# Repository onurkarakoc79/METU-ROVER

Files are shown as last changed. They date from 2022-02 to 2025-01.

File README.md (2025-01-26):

# METU Rover Project (2019–2022)
# Overview
The METU Rover project focuses on developing advanced robotics solutions for exploration, object detection, and autonomous navigation. During my involvement from 2019 to 2022, I contributed to various aspects of the project, including hardware integration, software development, and algorithm optimization.

# Features

* Object Detection: Implemented temperature-initiated object detection algorithms.
* Autonomous Navigation: Enhanced path planning and obstacle avoidance mechanisms.
* Modular Design: Ensured scalability and modularity in system design.

Setup Instructions
To clone the repository for one of my published modules:

```bash
   git clone https://github.com/onurkarakoc79/METU-ROVER
```
About METU Rover
Learn more about the METU Rover project at METU Rover Website.

<pre> https://meturover.com </pre>

## Contact

If you have any questions, feedback, or inquiries related to the project, feel free to reach out to me:

My personal mail: onurkarakoc79@gmail.com

I appreciate your interest in my projects and look forward to collaborating with you in the fascinating field of scientific exploration and discovery.

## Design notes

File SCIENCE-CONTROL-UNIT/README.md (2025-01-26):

# Metu Rover Science Control Unit

Welcome to the Metu Rover Science Control Unit! This repository contains the control card designs for Metu Rover Team's rover. The control cards play a crucial role in the rover's soil analysis and air sensor functions.

## Soil Analysis Unit

The Soil Analysis Unit is an essential component of the Metu Rover. It is mounted on the rover's back and is responsible for collecting soil data and analyzing it to determine the presence of living organisms. The unit utilizes advanced technologies to gather data and provides valuable insights into the composition and condition of the soil. The results obtained from the soil analysis aid in understanding the viability of potential habitats.

## Air Sensor Antenna

The Air Sensor Antenna is another integral part of Metu Rover's Analysis Unit. This antenna is designed to collect data from the surrounding air and analyze the air quality. By monitoring various parameters such as particulate matter, gases, and other relevant factors, the rover can assess the habitability of the planet or environment it is exploring. The data collected by the Air Sensor Antenna helps researchers and scientists make informed decisions about the suitability of an area for potential exploration or settlement.

## Contact

If you have any questions, feedback, or inquiries related to the project, feel free to reach out to me:

My personal mail: onurkarakoc79@gmail.com

I appreciate your interest in my projects and look forward to collaborating with you in the fascinating field of scientific exploration and discovery.

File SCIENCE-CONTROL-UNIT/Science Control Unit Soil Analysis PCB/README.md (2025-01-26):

# Metu Rover Soil Analysis PCB

## What the PCB is Designed For

The Soil Analysis Box is a crucial component of the Analysis Unit and is responsible for conducting soil analysis on the Metu Rover. The PCB (Printed Circuit Board) described here plays a significant role in controlling and managing various components within the Soil Analysis Box. The key features and functionalities of the Soil Analysis Box are as follows:

Drilling Mechanism: The box includes a driller for digging into the soil.

Vibration Motors: Four small vibration motors and three bmp280 pressure sensors are used to sift the earth and collect soil samples.

Servo Motors: Five servo motors are employed to pour certain chemicals into test tubes.

Stepper Motors: Five small stepper motors and one large stepper motor (Nema23) are used for precise movements and control.

Sensors: The analysis box incorporates three weight sensors, one soil moisture sensor, one temperature sensor, and three bmp280 pressure sensors to measure various soil properties

STM32 Microcontrollers: Two STM32 microcontrollers are utilized for faster processing and pin management. They are connected via UART communication protocol.

Data Transmission: The PCB facilitates the transmission of collected data from sensors to the main computer and subsequently to the base for further analysis.

Motor Control: The PCB determines the operating time of the motors and controls the number of steps the stepper motors will run.

## PCB Description

The PCB design takes into consideration the challenges associated with mounting SMD components and ensures easy replacement of the STM32 Blue Pill boards. The following key aspects are associated with the PCB design:

Dual STM32 Configuration: Two STM32 microcontrollers are utilized to distribute processing load and overcome pin shortage. UART communication is established between the two microcontrollers, with one acting as the primary communicator with the host while waking up the other for specific tasks.

Sensor Readings and Communication: The primary STM32 continuously reads data from the sensors and facilitates communication with the computer. It ensures a steady flow of information between the PCB and the host.

Motor Control: The secondary STM32, which is in a sleep state most of the time for power-saving purposes, determines the operating timing of the motors and controls the steps taken by the stepper motors.

Power and Ground Layers: The PCB consists of two layers, with the top layer dedicated to 5V, 3.3V, and VCC (24V) areas. The bottom layer is entirely covered by the GND line.

Power Supply: The PCB includes a voltage regulator to step down the primary 24V power input to 5V for the necessary sensors. The STM32's internal regulator provides the 3.3V line.

Communication: The PCB utilizes the CAN (Controller Area Network) module for communication with the host.

Motor Control and Integration: Vibration motors are controlled using transistors, while four stepper motor drivers are integrated directly into the circuit. Additionally, an external stepper driver stm is employed to activate the Nema23 large stepper motor.
Please note that this is a high-level overview of the Metu Rover Soil Analysis PCB. For more detailed information and technical specifications, please refer to the relevant documentation.

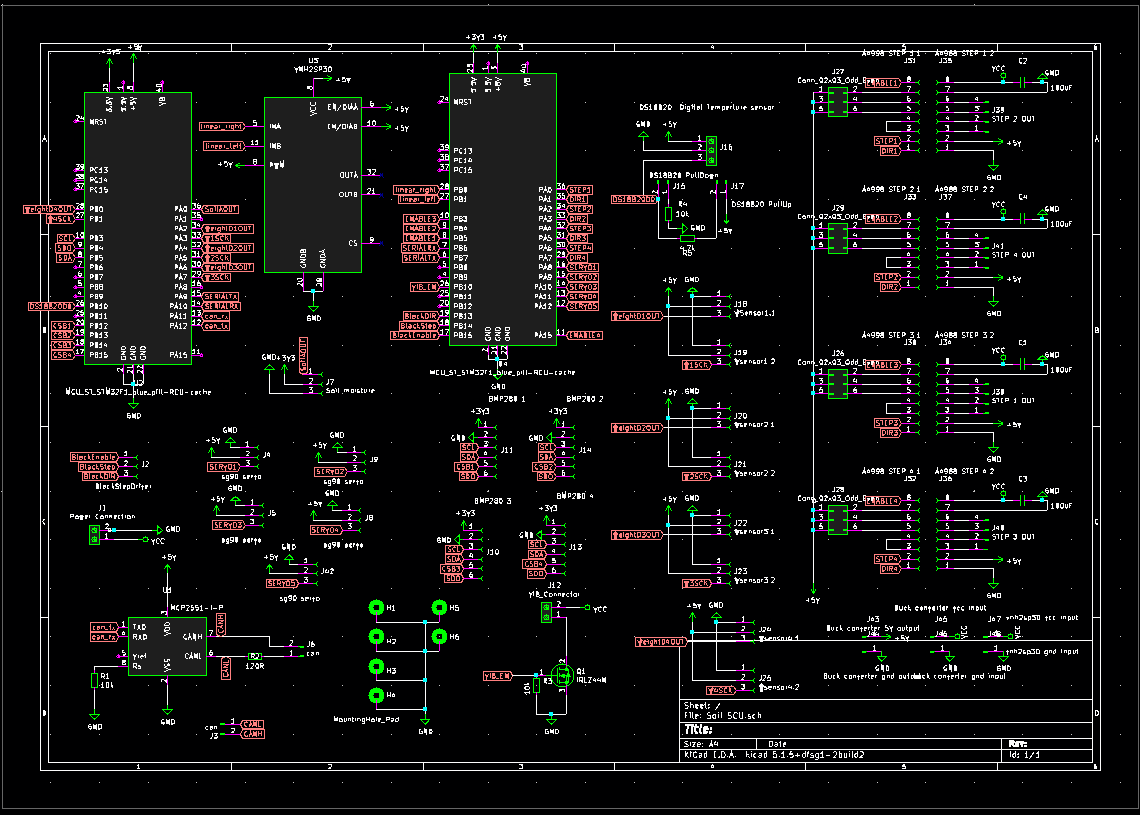
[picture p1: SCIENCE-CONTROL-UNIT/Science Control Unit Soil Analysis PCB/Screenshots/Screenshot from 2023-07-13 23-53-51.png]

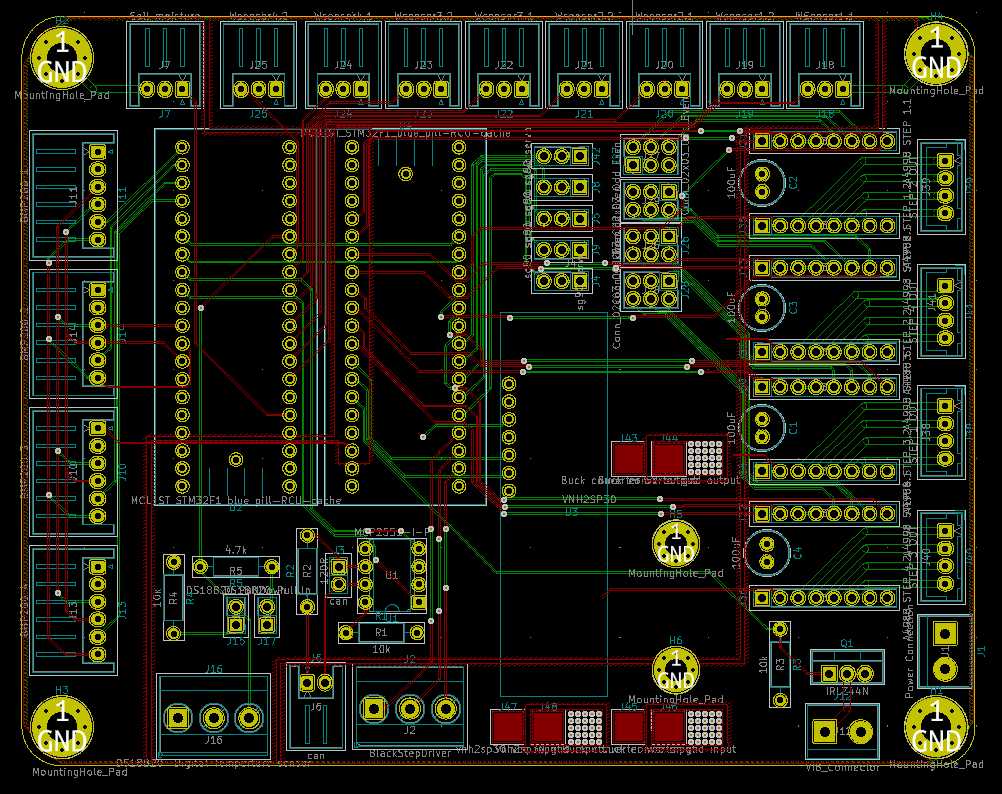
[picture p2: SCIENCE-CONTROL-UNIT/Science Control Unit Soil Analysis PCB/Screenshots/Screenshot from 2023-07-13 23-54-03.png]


## Contact

If you have any questions, feedback, or inquiries related to the project, feel free to reach out to me:

My personal mail: onurkarakoc79@gmail.com

I appreciate your interest in my projects and look forward to collaborating with you in the fascinating field of scientific exploration and discovery.

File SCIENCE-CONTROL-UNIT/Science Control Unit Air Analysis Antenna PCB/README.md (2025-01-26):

# PCB for Antenna Control and Sensor Interface
## What is the PCB Made For

The PCB designed for the antenna serves as a control card, providing essential functionality for the antenna system. It incorporates an STM32 microcontroller, six sensor inputs, and a CAN module for seamless communication with the host system. The antenna system is capable of detecting gases such as CO, CH4, and H2 using these sensors. Additionally, it can measure UV light intensity, airborne dust levels, and accurately determine air temperature and humidity. The STM32 processor reads and organizes the data from the sensors, which is then transmitted to the central control unit via the CAN module. From there, the data flows to the rover host (Nvidia Jetson TX2) and ultimately reaches the central control center with the assistance of Lora communication. The collected data is utilized for the projected thesis or other relevant purposes.

## PCB Description
The PCB designed for the antenna system exhibits a straightforward structure with the following features:

Sensor Inputs: The PCB provides six JST inputs for connecting the sensors. To ensure compatibility with the 3.3V operating voltage of the STM32 microcontroller, a voltage divider is implemented for sensor outputs that typically work with 5 volts.

Layer Structure: The PCB follows a 2-layer design. The first layer is dedicated to the 5V field, while the second layer is covered with the GND field, establishing a proper grounding structure.

Power Supply: Although the main power input to the PCB is 24V, a voltage regulator is employed to reduce the voltage to 5V, which is then supplied to the sensors. This ensures the sensors operate within their specified voltage range.

Interchangeability and Assembly: Instead of utilizing SMD components, the PCB is designed to accommodate female header pins, enabling easy assembly and interchangeability. This design choice allows the PCB to function as a basic breadboard and facilitates the placement of a ready-made STM32 Blue Pill module on it. 

As a result, the system can be used without the need for voltage level conversion from 5V to 3.3V for the STM32 microcontroller.
Please note that this is a summary of the key features of the antenna PCB. For more detailed technical specifications and information, please refer to the relevant documentation.

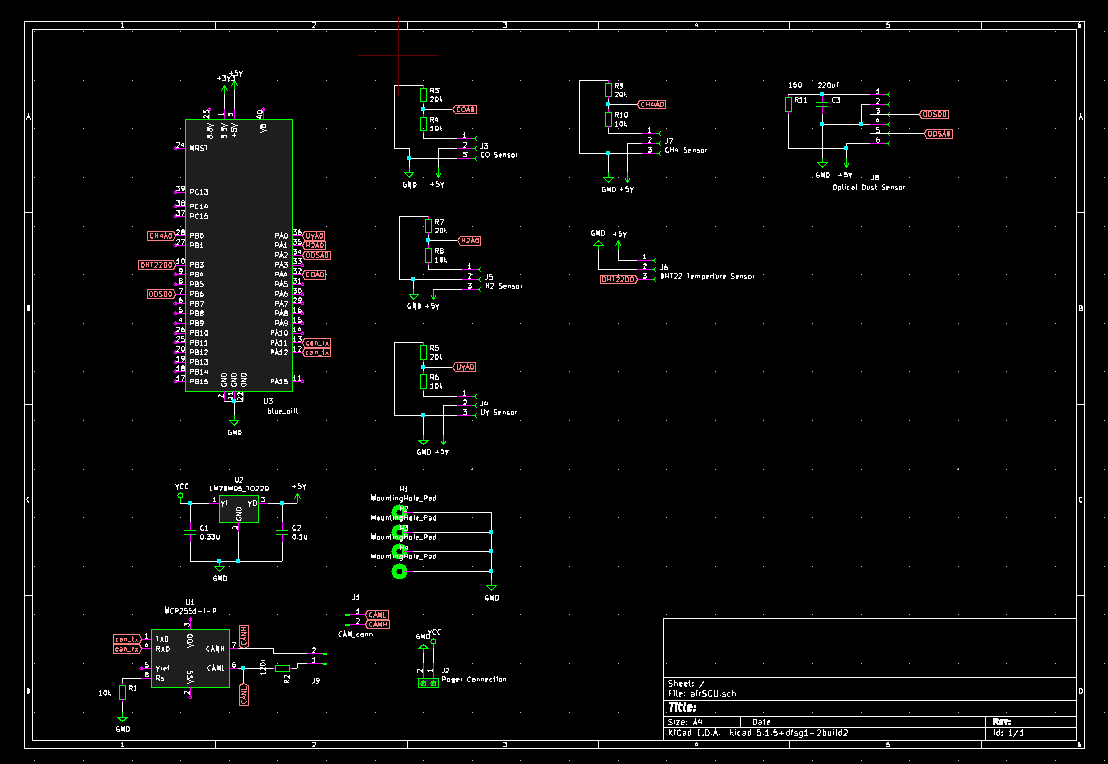
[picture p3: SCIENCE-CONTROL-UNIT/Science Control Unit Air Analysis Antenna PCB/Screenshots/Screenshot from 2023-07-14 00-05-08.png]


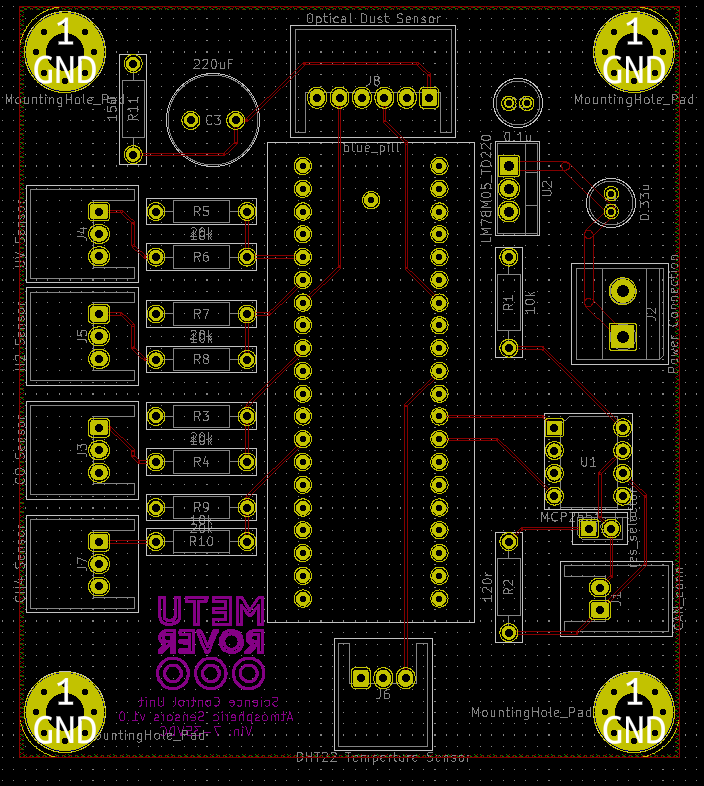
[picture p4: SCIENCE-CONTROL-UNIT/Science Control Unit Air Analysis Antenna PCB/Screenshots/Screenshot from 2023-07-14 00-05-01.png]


## Contact

If you have any questions, feedback, or inquiries related to the project, feel free to reach out to me:

My personal mail: onurkarakoc79@gmail.com

I appreciate your interest in my projects and look forward to collaborating with you in the fascinating field of scientific exploration and discovery.

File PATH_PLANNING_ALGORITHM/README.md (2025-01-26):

# Computer Vision Rover Path Planning

This is a path planning code for a rover developed using Python. The code utilizes Dijkstra's algorithm to find the shortest path between a given start point and an endpoint, considering obstacles in the environment. It is designed to work with images as input for computer vision applications.

## Features

- Calculation of the shortest path using Dijkstra's algorithm
- Handling of obstacles defined as convex shapes
- Visualization of the path on an input image
- Integration with computer vision applications

## Prerequisites

- Python 3. x

## Installation

1. Clone the repository to your local machine:

```bash
   git clone https://github.com/onurkarakoc79/METU-ROVER.git
```

3. Install requirement libraries
pip install -r requirements.txt

Usage
Configure the map and obstacle settings in the main() function of the Map.py file.
Prepare an input image of the map on which you want to perform path planning.
Run the path planning code:
shell
Copy code

python3 Map.py

After executing the Map.py file you don't need to execute it every time unless the map was changed.
After that execute the VisualwithClick.py file
Copy code

python3 VisualwithClick.py

Click on the image to specify the start and end points.
The calculated path will be displayed on the image.
You can close the window with the ESC button.

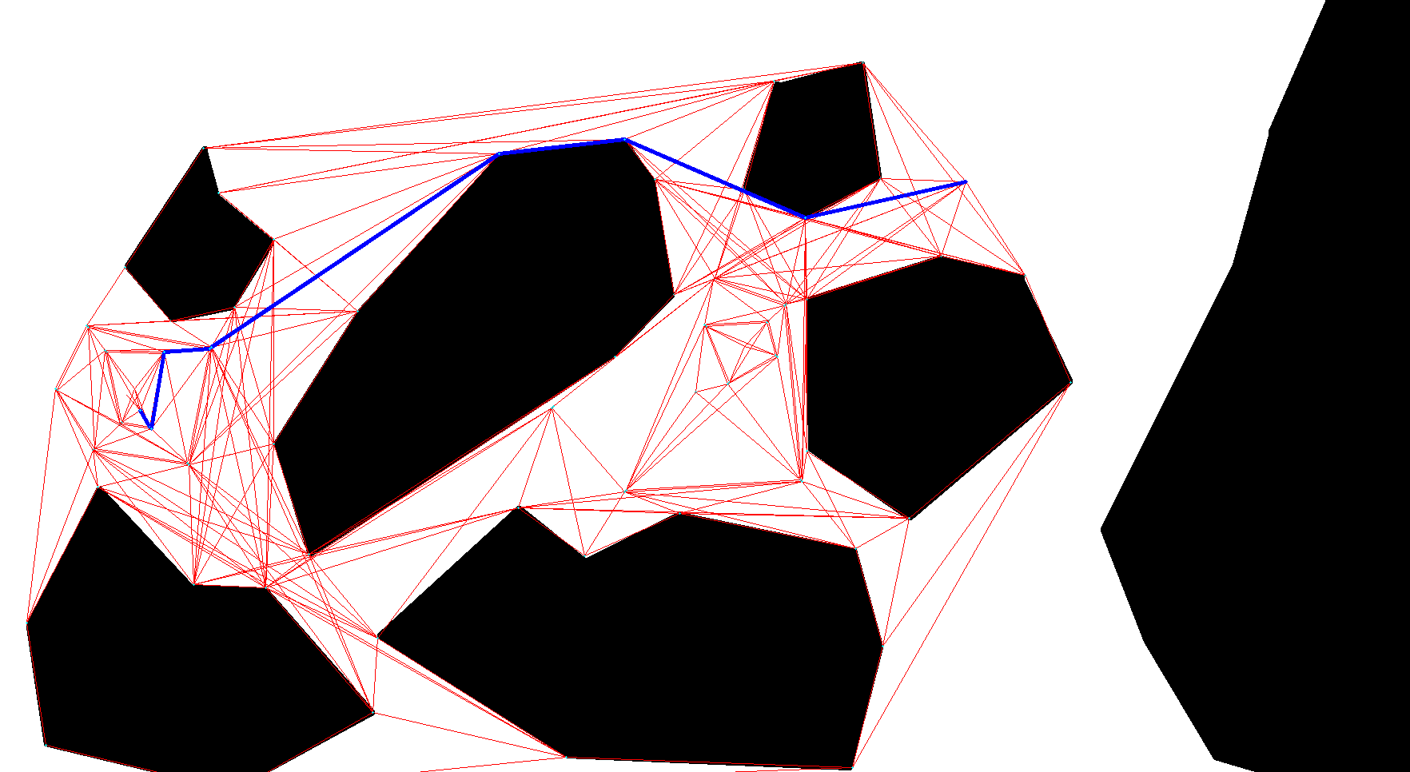
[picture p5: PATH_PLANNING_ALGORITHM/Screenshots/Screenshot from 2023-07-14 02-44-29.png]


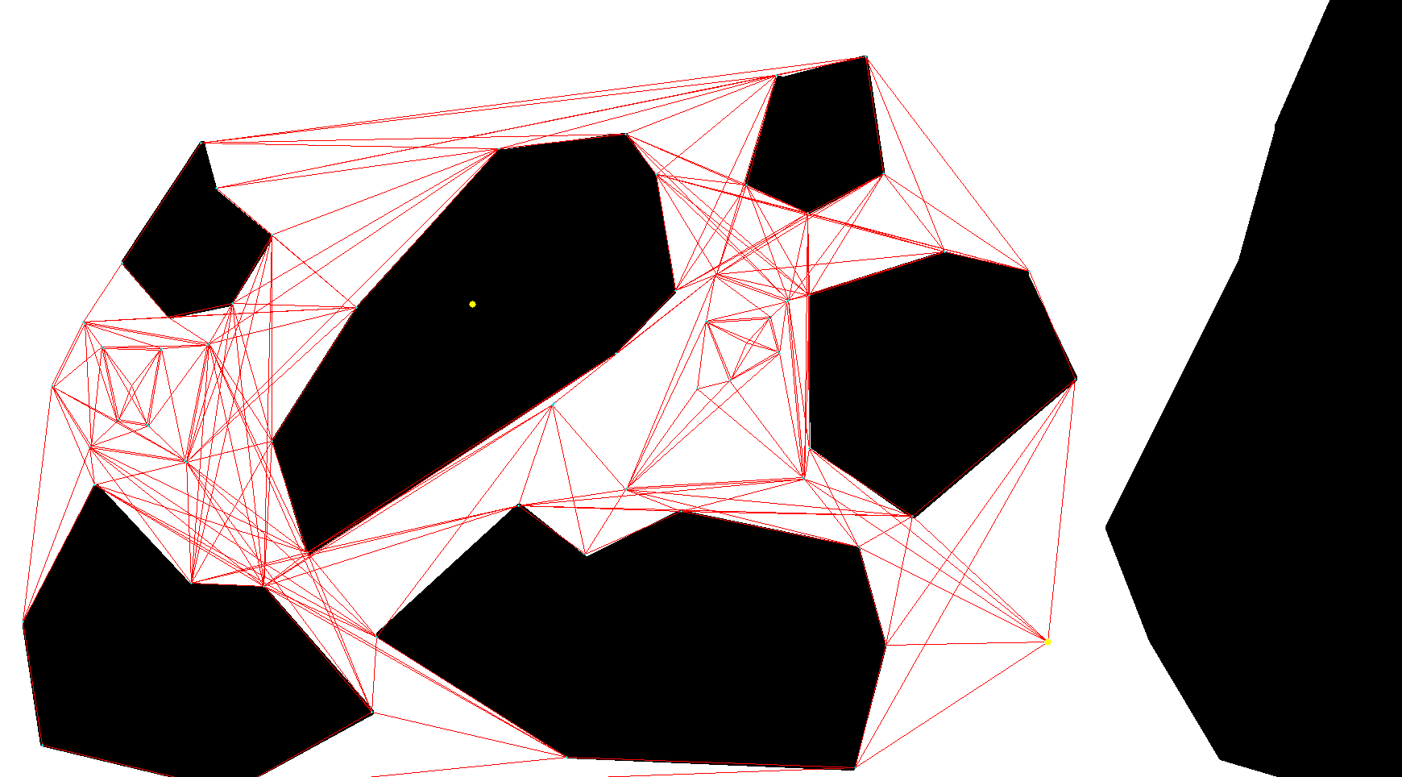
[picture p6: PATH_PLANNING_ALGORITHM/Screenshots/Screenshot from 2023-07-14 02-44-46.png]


## Contact

If you have any questions, feedback, or inquiries related to the project, feel free to reach out to me:

My personal mail: onurkarakoc79@gmail.com

I appreciate your interest in my projects and look forward to collaborating with you in the fascinating field of scientific exploration and discovery.

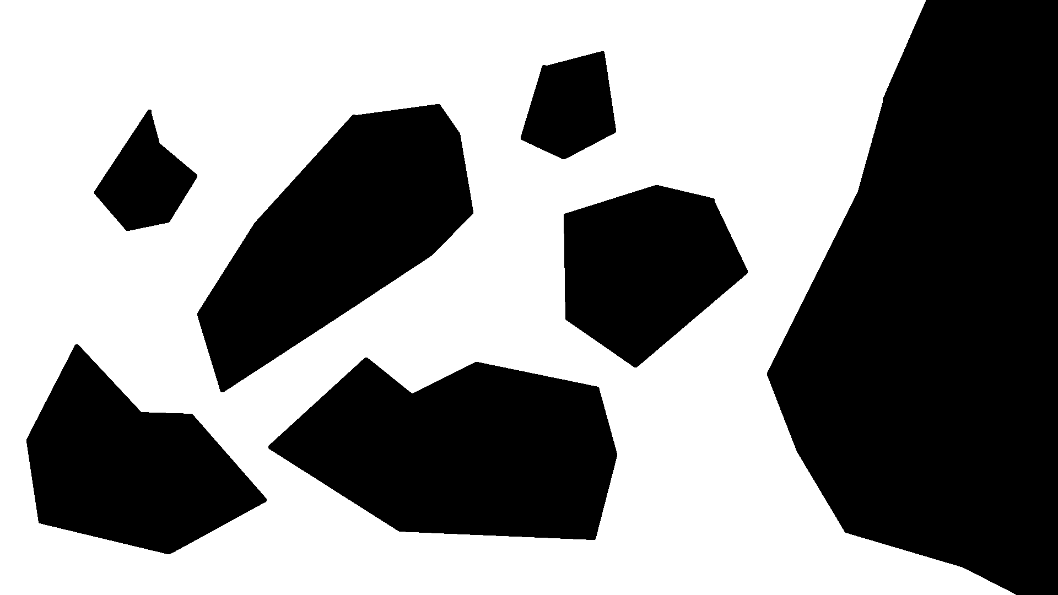
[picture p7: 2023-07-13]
PATH_PLANNING_ALGORITHM/map_01.png

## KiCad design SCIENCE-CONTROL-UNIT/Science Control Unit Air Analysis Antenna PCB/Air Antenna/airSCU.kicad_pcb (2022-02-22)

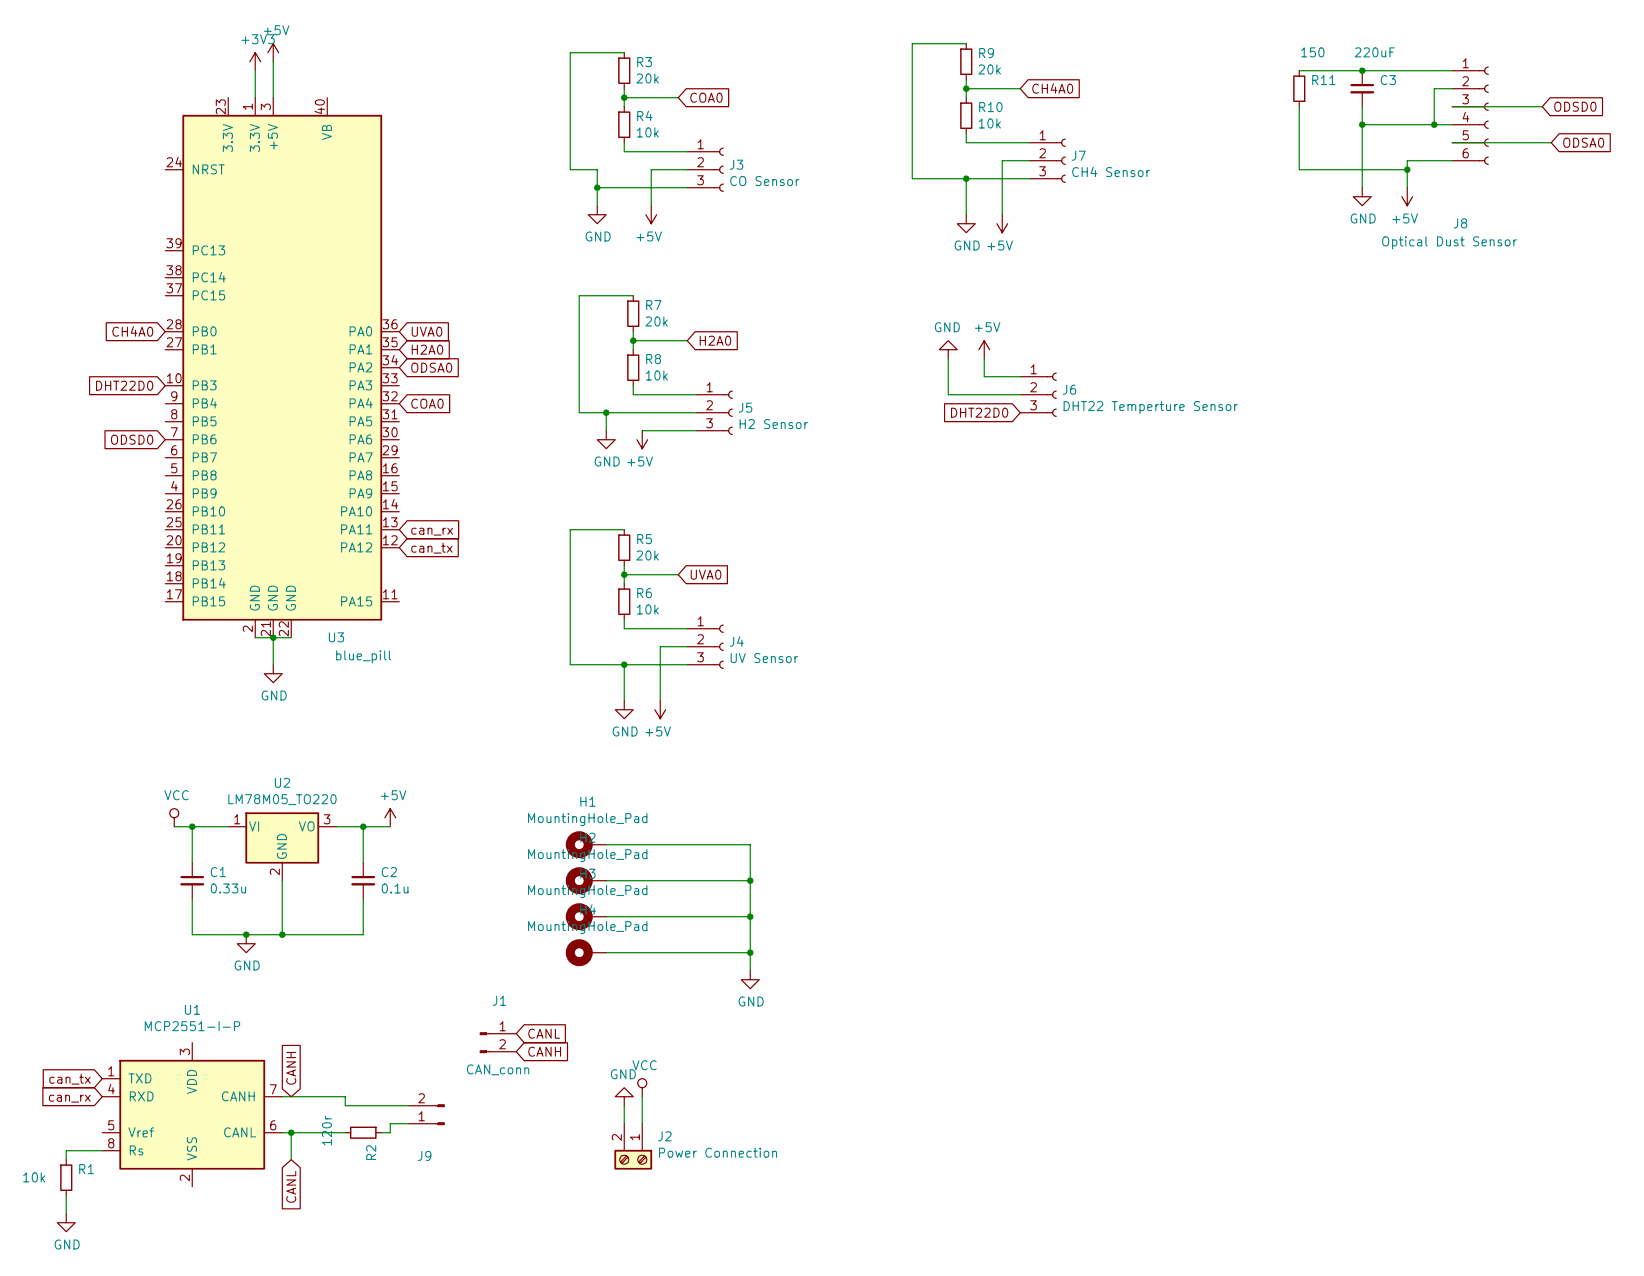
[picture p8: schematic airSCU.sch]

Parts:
C1: 0.33u; C_Radial_D5.0mm_H5.0mm_P2.00mm
C2: 0.1u; C_Radial_D5.0mm_H5.0mm_P2.00mm
C3: 220uF; C_Radial_D10.0mm_H12.5mm_P5.00mm
H1, H2, H3, H4: MountingHole_Pad; MountingHole_4.3mm_M4_Pad_Via
J1: CAN_conn; JST_XH_S2B-XH-A-1_1x02_P2.50mm_Horizontal
J2: Power Connection; TerminalBlock_Phoenix_MKDS-1,5-2-5.08_1x02_P5.08mm_Horizont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
J3: CO Sensor; JST_XH_S3B-XH-A-1_1x03_P2.50mm_Horizontal
J4: UV Sensor; JST_XH_S3B-XH-A-1_1x03_P2.50mm_Horizontal
J5: H2 Sensor; JST_XH_S3B-XH-A-1_1x03_P2.50mm_Horizontal
J6: DHT22 Temperture Sensor; JST_XH_S3B-XH-A-1_1x03_P2.50mm_Horizontal
J7: CH4 Sensor; JST_XH_S3B-XH-A-1_1x03_P2.50mm_Horizontal
J8: Optical Dust Sensor; JST_XH_S6B-XH-A-1_1x06_P2.50mm_Horizontal
J9: res_selector; PinHeader_1x02_P2.54mm_Vertical
R1, R4, R6, R8, R10: 10k; R_Axial_DIN0207_L6.3mm_D2.5mm_P10.16mm_Horizontal
R2: 120r; R_Axial_DIN0207_L6.3mm_D2.5mm_P10.16mm_Horizontal
R3, R5, R7, R9: 20k; R_Axial_DIN0207_L6.3mm_D2.5mm_P10.16mm_Horizontal
R11: 150; R_Axial_DIN0207_L6.3mm_D2.5mm_P10.16mm_Horizontal
U1: MCP2551-I-P; DIP-8_W7.62mm
U2: LM78M05_TO220; TO-220-3_Vertical
U3: blue_pill

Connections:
+3V3: U3.1 (3.3V)
+5V: C2.1, J3.2, J4.2, J5.3, J6.1, J7.2, J8.6, R11.1, U2.3 (VO), U3.3 (+5V)
CANH: J1.2, J9.2, U1.7 (CANH)
CANL: J1.1, R2.2, U1.6 (CANL)
CH4A0: R9.2, R10.1, U3.28 (PB0)
COA0: R3.2, R4.1, U3.32 (PA4)
DHT22D0: J6.3, U3.10 (PB3)
GND: C1.2, C2.2, C3.2, H1.1, H2.1, H3.1, H4.1, J2.2, J3.3, J4.3, J5.2, J6.2, J7.3, J8.2, J8.4, R1.2, R3.1, R5.1, R7.1, R9.1, U2.2 (GND), U3.2 (GND), U3.21 (GND), U3.22 (GND)
H2A0: R7.2, R8.1, U3.35 (PA1)
unnamed: C3.1, J8.1, R11.2
unnamed: J3.1, R4.2
unnamed: J4.1, R6.2
unnamed: J5.1, R8.2
unnamed: J7.1, R10.2
unnamed: J9.1, R2.1
unnamed: R1.1, U1.8 (Rs)
ODSA0: J8.5, U3.34 (PA2)
ODSD0: J8.3, U3.7 (PB6)
UVA0: R5.2, R6.1, U3.36 (PA0)
VCC: C1.1, J2.1, U2.1 (VI)
can_rx: U1.4 (RXD), U3.13 (PA11)
can_tx: U1.1 (TXD), U3.12 (PA12)

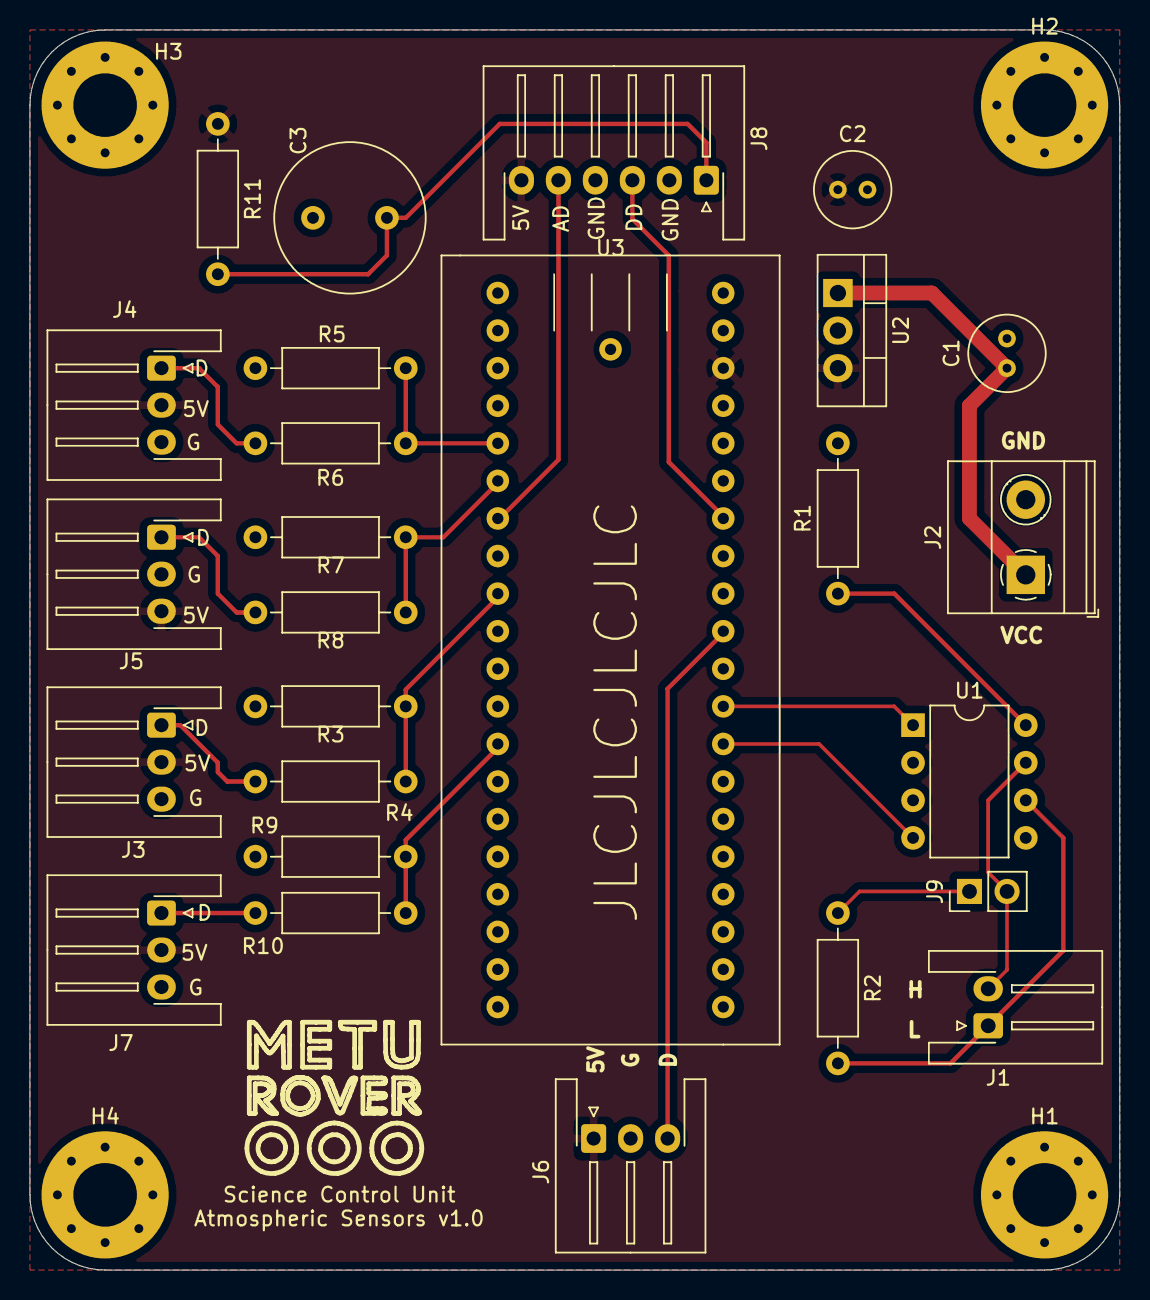
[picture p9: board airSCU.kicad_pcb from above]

Board: 2 copper layers, 73.7 x 83.8 mm, 30 parts (0 on the bottom side), 21 nets.

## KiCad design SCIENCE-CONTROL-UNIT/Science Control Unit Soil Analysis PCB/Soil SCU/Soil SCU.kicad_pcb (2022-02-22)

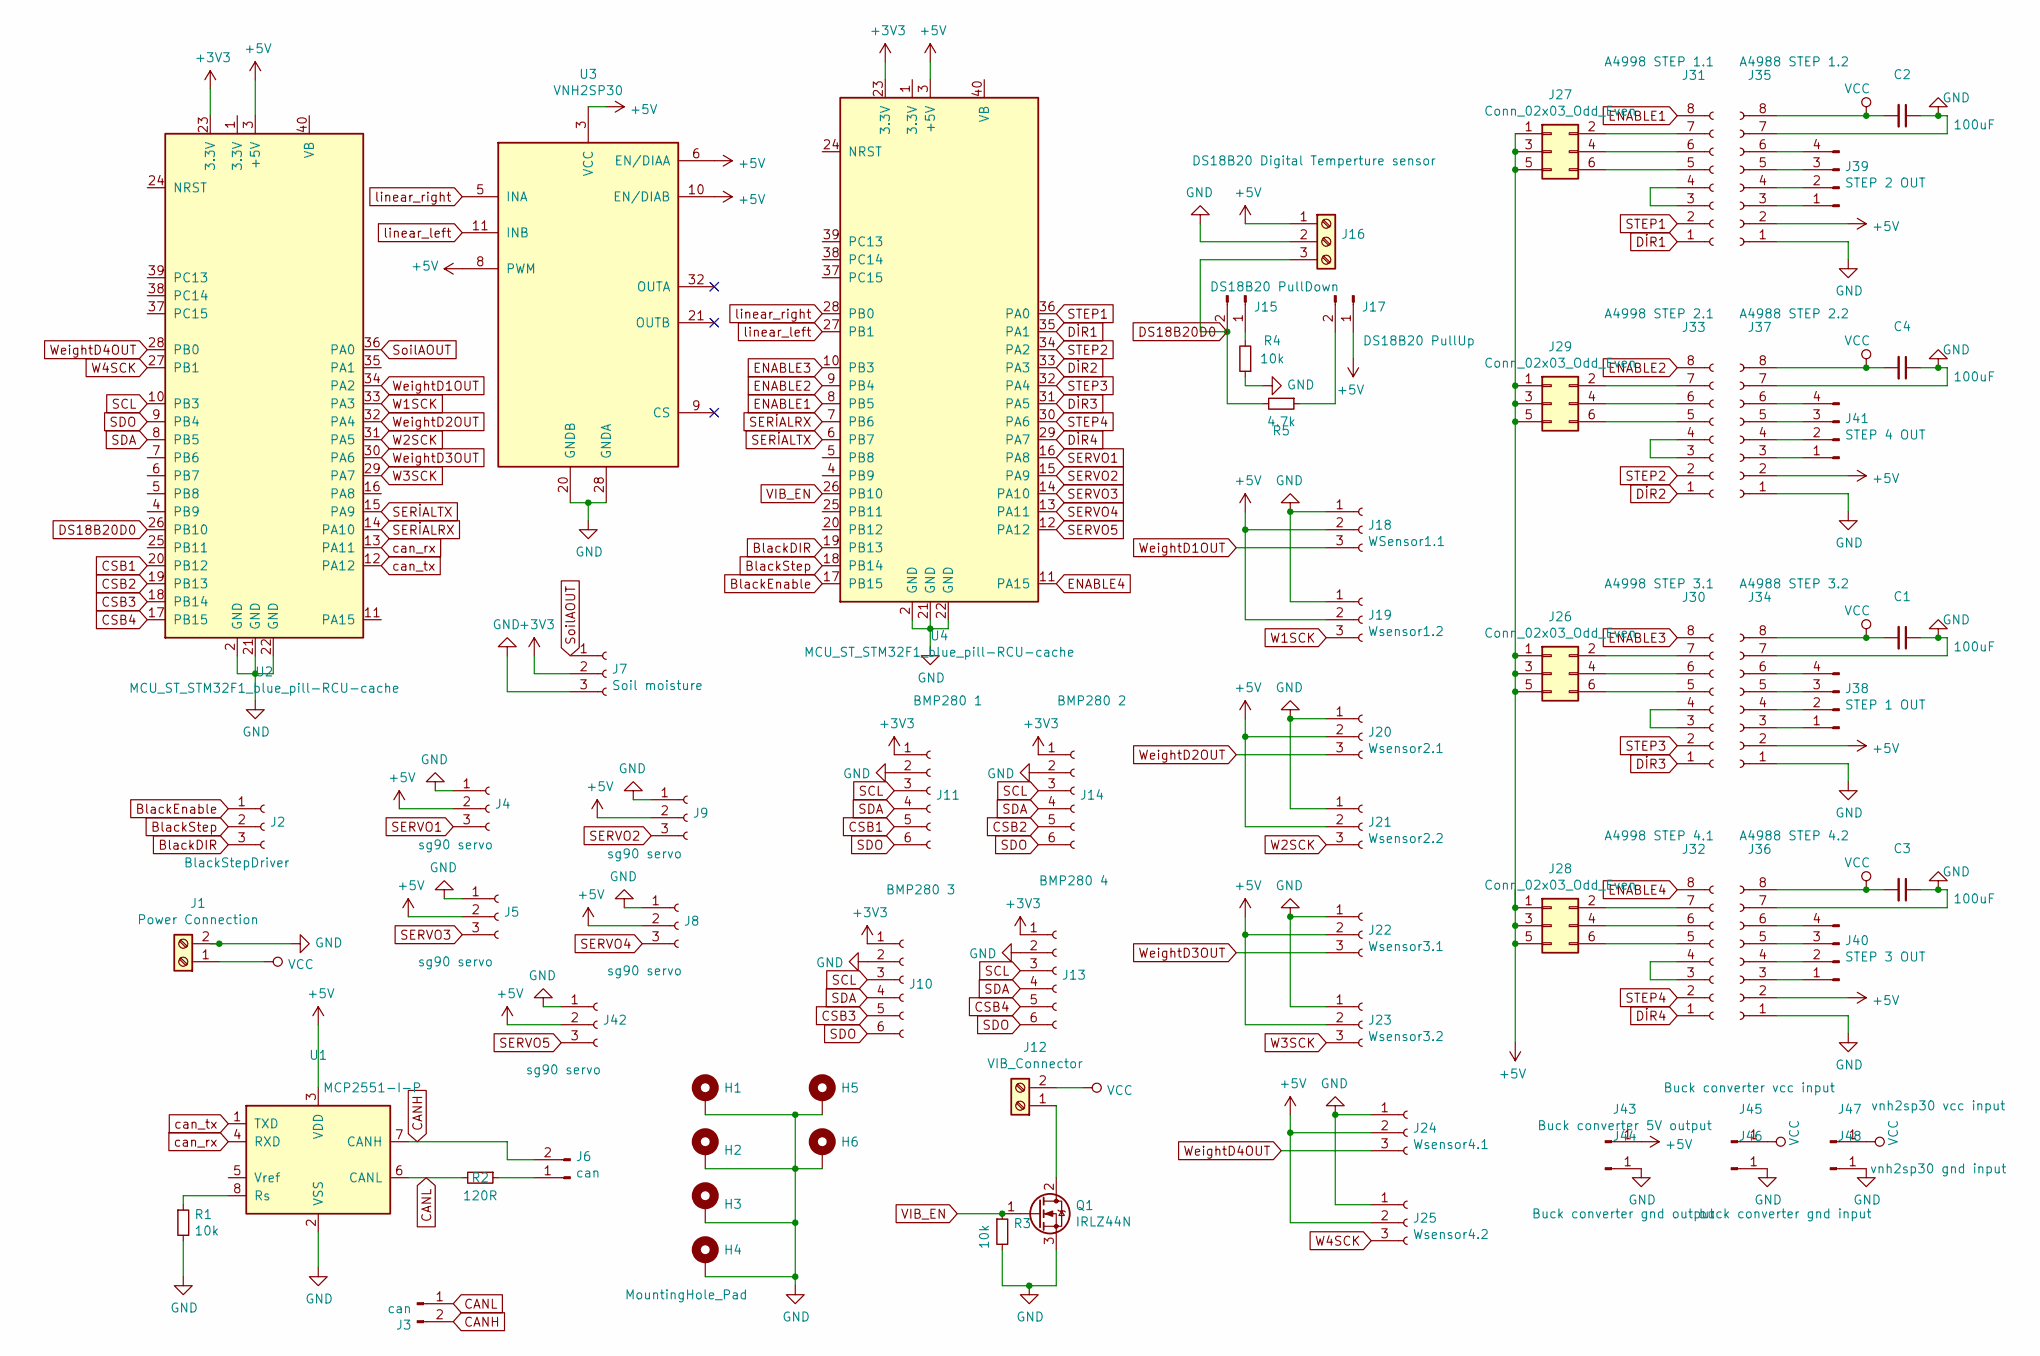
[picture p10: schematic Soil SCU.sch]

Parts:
C1, C2, C3, C4: 100uF; C_Radial_D6.3mm_H11.0mm_P2.50mm
H1, H2, H3, H4: MountingHole_Pad; MountingHole_4.3mm_M4_Pad_Via
H5, H6: MountingHole_Pad; MountingHole_3.2mm_M3_Pad_Via
J1: Power Connection; TerminalBlock_bornier-2_P5.08mm
J2: BlackStepDriver; TerminalBlock_Phoenix_MKDS-3-3-5.08_1x03_P5.08mm_Horizontal
J3: can; PinHeader_1x02_P2.54mm_Vertical
J4, J5, J8, J9, J42: sg90 servo; PinHeader_1x03_P2.54mm_Vertical
J6: can; JST_XH_S2B-XH-A_1x02_P2.50mm_Horizontal
J7: Soil moisture; JST_XH_S3B-XH-A_1x03_P2.50mm_Horizontal
J10: BMP280 3; JST_XH_S6B-XH-A_1x06_P2.50mm_Horizontal
J11: BMP280 1; JST_XH_S6B-XH-A_1x06_P2.50mm_Horizontal
J12: VIB_Connector; TerminalBlock_bornier-2_P5.08mm
J13: BMP280 4; JST_XH_S6B-XH-A_1x06_P2.50mm_Horizontal
J14: BMP280 2; JST_XH_S6B-XH-A_1x06_P2.50mm_Horizontal
J15: DS18B20 PullDown; PinHeader_1x02_P2.54mm_Vertical
J16: DS18B20 Digital Temperture sensor; TerminalBlock_Phoenix_MKDS-3-3-5.08_1x03_P5.08mm_Horizontal
J17: DS18B20 PullUp; PinHeader_1x02_P2.54mm_Vertical
J18: WSensor1.1; JST_XH_S3B-XH-A_1x03_P2.50mm_Horizontal
J19: Wsensor1.2; JST_XH_S3B-XH-A_1x03_P2.50mm_Horizontal
J20: Wsensor2.1; JST_XH_S3B-XH-A_1x03_P2.50mm_Horizontal
J21: Wsensor2.2; JST_XH_S3B-XH-A_1x03_P2.50mm_Horizontal
J22: Wsensor3.1; JST_XH_S3B-XH-A_1x03_P2.50mm_Horizontal
J23: Wsensor3.2; JST_XH_S3B-XH-A_1x03_P2.50mm_Horizontal
J24: Wsensor4.1; JST_XH_S3B-XH-A_1x03_P2.50mm_Horizontal
J25: Wsensor4.2; JST_XH_S3B-XH-A_1x03_P2.50mm_Horizontal
J26, J27, J28, J29: Conn_02x03_Odd_Even; PinHeader_2x03_P2.54mm_Vertical
J30: A4998 STEP 3.1; PinSocket_1x08_P2.54mm_Vertical
J31: A4998 STEP 1.1; PinSocket_1x08_P2.54mm_Vertical
J32: A4998 STEP 4.1; PinSocket_1x08_P2.54mm_Vertical
J33: A4998 STEP 2.1; PinSocket_1x08_P2.54mm_Vertical
J34: A4988 STEP 3.2; PinSocket_1x08_P2.54mm_Vertical
J35: A4988 STEP 1.2; PinSocket_1x08_P2.54mm_Vertical
J36: A4988 STEP 4.2; PinSocket_1x08_P2.54mm_Vertical
J37: A4988 STEP 2.2; PinSocket_1x08_P2.54mm_Vertical
J38: STEP 1 OUT; JST_XH_B4B-XH-A_1x04_P2.50mm_Vertical
J39: STEP 2 OUT; JST_XH_B4B-XH-A_1x04_P2.50mm_Vertical
J40: STEP 3 OUT; JST_XH_B4B-XH-A_1x04_P2.50mm_Vertical
J41: STEP 4 OUT; JST_XH_B4B-XH-A_1x04_P2.50mm_Vertical
J43: Buck converter 5V output; TestPoint_Pad_4.0x4.0mm
J44: Buck converter gnd output; TestPoint_Pad_4.0x4.0mm
J45: Buck converter vcc input; TestPoint_Pad_4.0x4.0mm
J46: buck converter gnd input; TestPoint_Pad_4.0x4.0mm
J47: vnh2sp30 vcc input; TestPoint_Pad_4.0x4.0mm
J48: vnh2sp30 gnd input; TestPoint_Pad_4.0x4.0mm
Q1: IRLZ44N; TO-220-3_Vertical
R1, R3, R4: 10k; R_Axial_DIN0207_L6.3mm_D2.5mm_P10.16mm_Horizontal
R2: 120R; R_Axial_DIN0207_L6.3mm_D2.5mm_P10.16mm_Horizontal
R5: 4.7k; R_Axial_DIN0207_L6.3mm_D2.5mm_P10.16mm_Horizontal
U1: MCP2551-I-P; DIP-8_W7.62mm
U2, U4: MCU_ST_STM32F1_blue_pill-RCU-cache; blue_pill
U3: VNH2SP30; vnh_vertical

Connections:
+3V3: J7.2, J10.1, J11.1, J13.1, J14.1, U2.23 (3.3V), U4.23 (3.3V)
+5V: J4.2, J5.2, J8.2, J9.2, J16.1, J17.1, J18.2, J19.2, J20.2, J21.2, J22.2, J23.2, J24.2, J25.2, J26.1, J26.3, J26.5, J27.1, J27.3, J27.5, J28.1, J28.3, J28.5, J29.1, J29.3, J29.5, J34.2, J35.2, J36.2, J37.2, J42.2, J43.1, U1.3 (VDD), U2.3 (+5V), U3.3 (VCC), U3.6 (EN/DIAA), U3.8 (PWM), U3.10 (EN/DIAB), U3.13 (VCC), U3.23 (VCC), U3.31 (VCC), U4.3 (+5V)
BlackDIR: J2.3, U4.19 (PB13)
BlackEnable: J2.1, U4.17 (PB15)
BlackStep: J2.2, U4.18 (PB14)
CANH: J3.2, J6.2, U1.7 (CANH)
CANL: J3.1, R2.2, U1.6 (CANL)
CSB1: J11.5, U2.20 (PB12)
CSB2: J14.5, U2.19 (PB13)
CSB3: J10.5, U2.18 (PB14)
CSB4: J13.5, U2.17 (PB15)
DS18B20D0: J15.2, J16.3, R5.2, U2.26 (PB10)
DİR1: J31.1, U4.35 (PA1)
DİR2: J33.1, U4.33 (PA3)
DİR3: J30.1, U4.31 (PA5)
DİR4: J32.1, U4.29 (PA7)
ENABLE1: J31.8, U4.8 (PB5)
ENABLE2: J33.8, U4.9 (PB4)
ENABLE3: J30.8, U4.10 (PB3)
ENABLE4: J32.8, U4.11 (PA15)
GND: C1.1, C2.1, C3.1, C4.1, H1.1, H2.1, H3.1, H4.1, H5.1, H6.1, J1.2, J4.1, J5.1, J7.3, J8.1, J9.1, J10.2, J11.2, J13.2, J14.2, J16.2, J18.1, J19.1, J20.1, J21.1, J22.1, J23.1, J24.1, J25.1, J34.1, J34.7, J35.1, J35.7, J36.1, J36.7, J37.1, J37.7, J42.1, J44.1, J46.1, J48.1, Q1.3 (S), R1.2, R3.2, R4.1, U1.2 (VSS), U2.2 (GND), U2.21 (GND), U2.22 (GND), U3.18 (GNDB), U3.19 (GNDB), U3.20 (GNDB), U3.26 (GNDA), U3.27 (GNDA), U3.28 (GNDA), U4.2 (GND), U4.21 (GND), U4.22 (GND)
unnamed: J6.1, R2.1
unnamed: J12.1, Q1.2 (D)
unnamed: J15.1, R4.2
unnamed: J17.2, R5.1
unnamed: J26.2, J30.7
unnamed: J26.4, J30.6
unnamed: J26.6, J30.5
unnamed: J27.2, J31.7
unnamed: J27.4, J31.6
unnamed: J27.6, J31.5
unnamed: J28.2, J32.7
unnamed: J28.4, J32.6
unnamed: J28.6, J32.5
unnamed: J29.2, J33.7
unnamed: J29.4, J33.6
unnamed: J29.6, J33.5
unnamed: J30.3, J30.4
unnamed: J31.3, J31.4
unnamed: J32.3, J32.4
unnamed: J33.3, J33.4
unnamed: J34.3, J38.1
unnamed: J34.4, J38.2
unnamed: J34.5, J38.3
unnamed: J34.6, J38.4
unnamed: J35.3, J39.1
unnamed: J35.4, J39.2
unnamed: J35.5, J39.3
unnamed: J35.6, J39.4
unnamed: J36.3, J40.1
unnamed: J36.4, J40.2
unnamed: J36.5, J40.3
unnamed: J36.6, J40.4
unnamed: J37.3, J41.1
unnamed: J37.4, J41.2
unnamed: J37.5, J41.3
unnamed: J37.6, J41.4
unnamed: R1.1, U1.8 (Rs)
SCL: J10.3, J11.3, J13.3, J14.3, U2.10 (PB3)
SDA: J10.4, J11.4, J13.4, J14.4, U2.8 (PB5)
SDO: J10.6, J11.6, J13.6, J14.6, U2.9 (PB4)
SERVO1: J4.3, U4.16 (PA8)
SERVO2: J9.3, U4.15 (PA9)
SERVO3: J5.3, U4.14 (PA10)
SERVO4: J8.3, U4.13 (PA11)
SERVO5: J42.3, U4.12 (PA12)
SERİALRX: U2.14 (PA10), U4.7 (PB6)
SERİALTX: U2.15 (PA9), U4.6 (PB7)
STEP1: J31.2, U4.36 (PA0)
STEP2: J33.2, U4.34 (PA2)
STEP3: J30.2, U4.32 (PA4)
STEP4: J32.2, U4.30 (PA6)
SoilAOUT: J7.1, U2.36 (PA0)
VCC: C1.2, C2.2, C3.2, C4.2, J1.1, J12.2, J34.8, J35.8, J36.8, J37.8, J45.1, J47.1
VIB_EN: Q1.1 (G), R3.1, U4.26 (PB10)
W1SCK: J19.3, U2.33 (PA3)
W2SCK: J21.3, U2.31 (PA5)
W3SCK: J23.3, U2.29 (PA7)
W4SCK: J25.3, U2.27 (PB1)
WeightD1OUT: J18.3, U2.34 (PA2)
WeightD2OUT: J20.3, U2.32 (PA4)
WeightD3OUT: J22.3, U2.30 (PA6)
WeightD4OUT: J24.3, U2.28 (PB0)
can_rx: U1.4 (RXD), U2.13 (PA11)
can_tx: U1.1 (TXD), U2.12 (PA12)
linear_left: U3.11 (INB), U4.27 (PB1)
linear_right: U3.5 (INA), U4.28 (PB0)

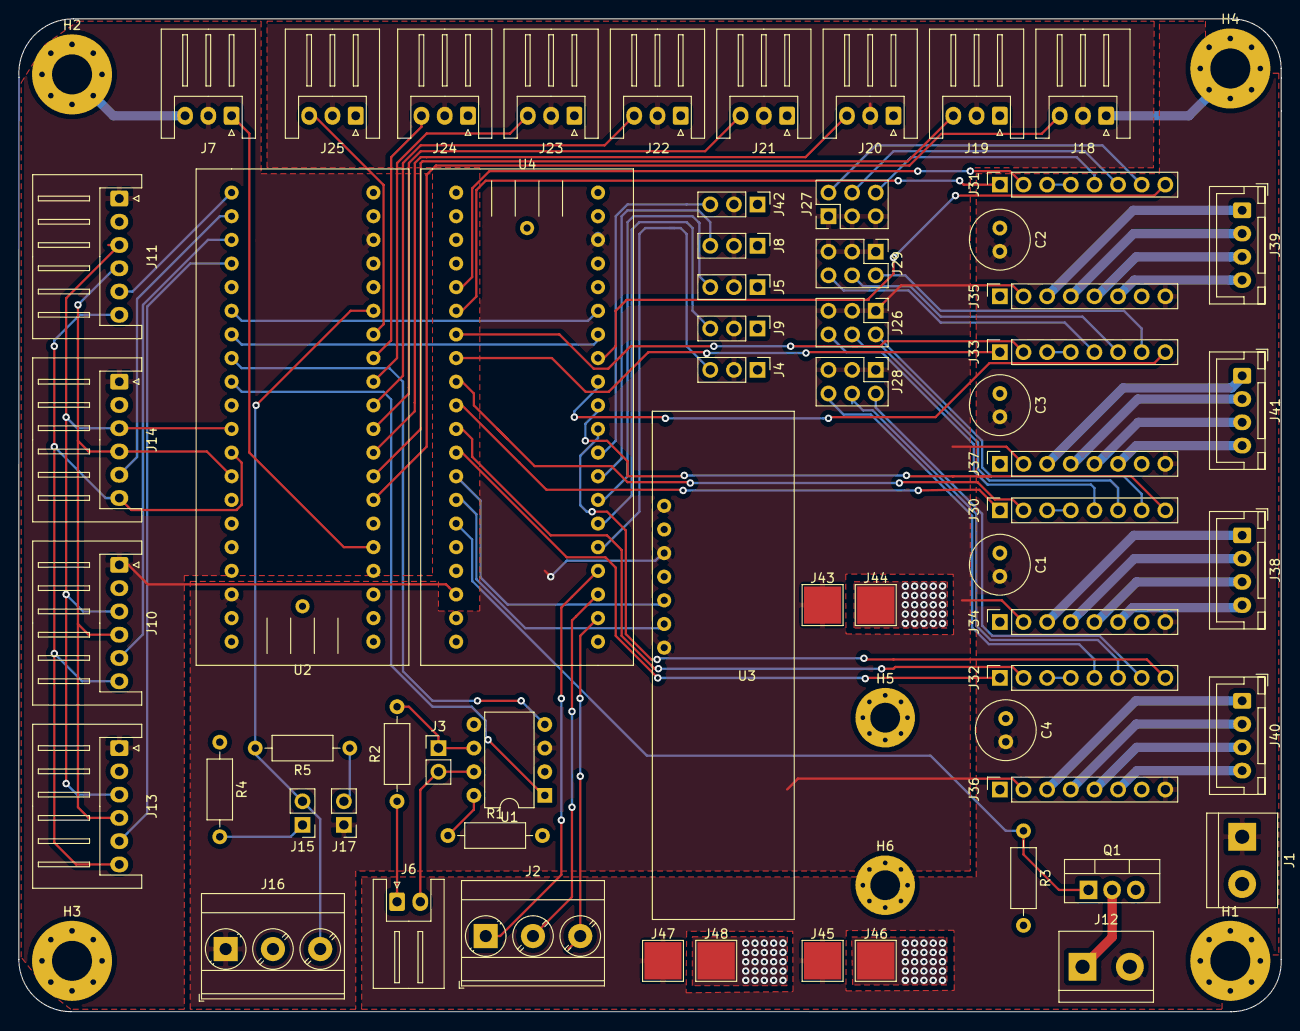
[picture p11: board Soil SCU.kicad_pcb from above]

Board: 2 copper layers, 135.6 x 106.7 mm, 68 parts (0 on the bottom side), 87 nets.
